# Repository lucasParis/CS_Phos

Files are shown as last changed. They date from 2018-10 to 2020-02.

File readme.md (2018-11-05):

Phos
===

USB Serial Protocol for Led Controllers
---
There is one led controller per side of the led pilar.
Each controller is being streamed frames 60 times a second of the leds' brightness by USB serial.
The protocol for the serial transmition consists of a __start byte of 255__ followed by a __list of 3564 bytes of brightness values between 0 and 254__.
These brightness values correspond to each pixel of the strip in series. The strips are arranged in 9 colomns, each with 11 modules of 36pixels long -i.e. 396 leds per colomn.
The data is listed one colomn after the other, starting and the top of the left colomn and making it's way down and then to the next colomn.
Serial baud is 2500000.

Arduino
---
- FastLED version 3.1.6
- Arduino 1.8.2
- Teensyloader 1.26

The best settings to avoid glitches in the apa102 data seems to be:
- teensy clock speed set to 144mhz
- fastled rate 3mhz

Serial baud is 2500000.

The _testCode_ firmware of prototype 2 loops 2 white leds through the strip.

Assembly
---
ribbon cables
power

TouchDesigner patch
---
### prototype 1
Test patch with internally generated patterns and UI to adjust patterns
### prototype 2
streaming patch, with syphon/spout input (to do).
- [ ] add syphon/spout input
- [ ] cleanup UI
- [ ] adapt test patterns from prototype 1
- [ ] add processing example code
- [ ] change total output for only 3 boxes, 1 side

Files
---
- prototype 1
  - Made in september 2018 for tests at the barbican
  - 1 box, 5 strips
- prototype 2
  - Made in October/November 2018
  - 3 boxes, 9 strips, 2 sides
  - custom pcbs version 1, with small changes needed
  - digikey BOMs

BOMs
---

#### BOM_leds_oneBoxSide_digikey

Bill of materials for 1 side of the box, includes power supply and connectors for 6 led breakout pcbs.
2 needed per box.

####  BOM_masterModule_digikey

Bill of materials for master module

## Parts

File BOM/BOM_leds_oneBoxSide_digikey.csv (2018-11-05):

Manufacturer Part Number | Manufacturer | Digi-Key Part Number | Customer Reference | Reference Designator | Packaging | Part Status | Quantity | Unit Price | Extended Price | Quantity Available | Mfg Std Lead Time | Description | RoHS Status | Lead Free Status | REACH Status
OSTYK42102030 | On Shore Technology Inc. | ED2945-ND |  |  | Bulk | Active | 6 | 1.18000 | $7.08 | 9870 | 12 Weeks | CONN BARRIER STRIP 2CIRC 0.325" | RoHS Compliant | Lead free | REACH Unaffected
5-520314-4 | TE Connectivity AMP Connectors | A123168-ND |  |  | Tray | Active | 18 | 0.82800 | $14.90 | 4437 | 18 Weeks | CONN FFC FPC TOP 4POS 2.54MM R/A | RoHS Compliant | Lead free | Not Available
30310-6002HB | 3M | 30310-6002HB-ND |  |  | Bulk | Active | 6 | 0.91000 | $5.46 | 18679 | 7 Weeks | CONN HEADER 10POS DL STR GOLD | RoHS Compliant | Lead free | Not Available
UHP-200A-5 | MEAN WELL USA Inc. | 1866-5498-ND |  |  | Box | Active | 1 | 69.31000 | $69.31 | 45 | Not Available | AC/DC CONVERTER 5V 200W | RoHS Compliant | Lead free | Not Available
D89110-0131HK-3365/10-D-3 | 3M | 3M156030-MC10G-3M156030-3-ND |  |  | Bulk | Active | 3 | 2.25000 | $6.75 | 237 | Not Available | CABLE 10POS SOCKET TO SOCKET 3" | RoHS Compliant | Lead free | Not Available
AK500-OE-11-1.5 | Assmann WSW Components | AE9912-ND |  |  | Bulk | Active | 1 | 6.82000 | $6.82 | 1189 | 20 Weeks | CORD SVT 18AWG 3COND 1.5M BLK | RoHS Compliant | Lead free | REACH Unaffected
0190980018 | Molex, LLC | WM13758-ND |  |  | Bulk | Active | 18 | 0.24600 | $4.42 | 4260 | 4 Weeks | CONN SPADE TERM 18-22AWG #6 | RoHS Compliant | Lead free | REACH Unaffected

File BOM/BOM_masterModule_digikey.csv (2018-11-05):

Manufacturer Part Number | Manufacturer | Digi-Key Part Number | Customer Reference | Reference Designator | Packaging | Part Status | Quantity | Unit Price | Extended Price | Quantity Available | Mfg Std Lead Time | Description | RoHS Status | Lead Free Status | REACH Status
SN74HCT245DWR | Texas Instruments | 296-1208-1-ND |  |  | Cut Tape (CT) | Active | 3 | 1.06000 | $3.18 | 11714 | 8 Weeks | IC TXRX NON-INVERT 5.5V 20SOIC | RoHS Compliant | Lead free | REACH Unaffected
4816P-T01-101LF | Bourns Inc. | 4816P-T01-101LF-ND |  |  | Tube | Active | 3 | 1.69000 | $5.07 | 548 | 7 Weeks | RES ARRAY 8 RES 100 OHM 16SOIC | RoHS Compliant | Lead free | REACH Unaffected
30310-6002HB | 3M | 30310-6002HB-ND |  |  | Bulk | Active | 3 | 0.91000 | $2.73 | 18679 | 7 Weeks | CONN HEADER 10POS DL STR GOLD | RoHS Compliant | Lead free | Not Available
OSTVN02A150 | On Shore Technology Inc. | ED10561-ND |  |  | Bulk | Active | 1 | 1.29000 | $1.29 | 33001 | 12 Weeks | CONN TERM BLOCK 2.54MM 2POS PCB | RoHS Compliant | Lead free | REACH Unaffected
61729-0010BLF | Amphenol FCI | 609-1039-ND |  |  | Tube | Active | 1 | 1.37000 | $1.37 | 32899 | 8 Weeks | CONN RCPT USB TYPE B R/A PCB | RoHS Compliant | Lead free | Not Available
GRM31CR71H105KA61L | Murata Electronics North America | 490-3908-1-ND |  |  | Cut Tape (CT) | Active | 3 | 0.55000 | $1.65 | 20000 | Not Available | CAP CER 1UF 50V X7R 1206 | RoHS Compliant | Lead free | Not Available
DEV-14057 | SparkFun Electronics | 1568-1442-ND |  |  | Bulk | Active | 1 | 46.02000 | $46.02 | 1141 | 8 Weeks | TEENSY 3.6 | Not applicable | Lead free | Not Available
HDR100IMP40F-G-V-TH | Chip Quik Inc. | HDR100IMP40F-G-V-TH-ND |  |  | Bulk | Active | 2 | 1.54000 | $3.08 | 1697 | 4 Weeks | 0.1" 40 PIN VERTICAL FEMALE HEAD | RoHS Compliant | Lead free | REACH Unaffected
61304011121 | Wurth Electronics Inc. | 732-5334-ND |  |  | Bag | Active | 2 | 2.04000 | $4.08 | 2631 | 14 Weeks | CONN HEADER 40 POS 2.54 | RoHS Compliant | Lead free | REACH Unaffected
H3DDH-1018G | Assmann WSW Components | H3DDH-1018G-ND |  |  | Bulk | Active | 3 | 2.14000 | $6.42 | 0 | Not Available | IDC CBL - HHKR10H/AE10G/HHKR10H | RoHS Compliant | Lead free | REACH Unaffected

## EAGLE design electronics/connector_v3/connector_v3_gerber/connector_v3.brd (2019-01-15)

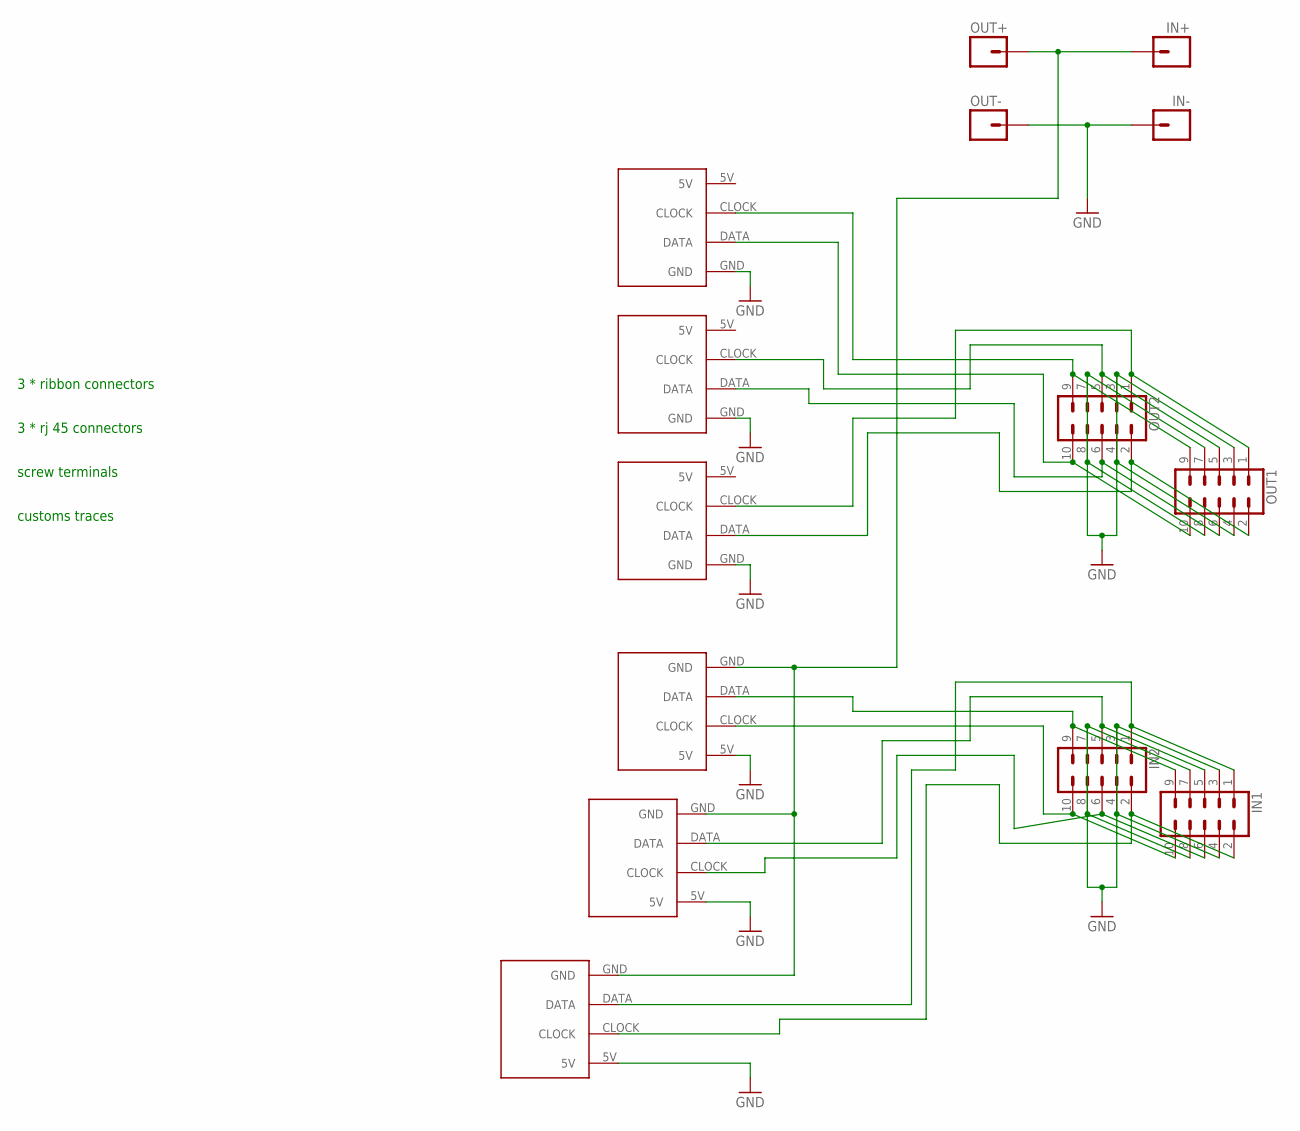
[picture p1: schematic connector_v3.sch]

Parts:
IN1, IN2: CONN_05X2SHD_LOCK; 2X5-SHROUDED_LOCK
IN+: M01PTH_2MM; 1X01_2MM
IN-: M01PTH_2MM; 1X01_2MM
INSTRIP1, INSTRIP2, INSTRIP3: APA102STRIP
OUT1, OUT2: CONN_05X2SHD_LOCK; 2X5-SHROUDED_LOCK
OUT+: M01PTH_2MM; 1X01_2MM
OUT-: M01PTH_2MM; 1X01_2MM
OUTSTRIP1, OUTSTRIP2, OUTSTRIP3: APA102STRIP

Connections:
GND: IN1.3, IN1.4, IN1.7, IN1.8, IN2.3, IN2.4, IN2.7, IN2.8, IN-.1, INSTRIP1.5V, INSTRIP2.5V, INSTRIP3.5V, OUT1.3, OUT1.4, OUT1.7, OUT1.8, OUT2.3, OUT2.4, OUT2.7, OUT2.8, OUT-.1, OUTSTRIP1.GND, OUTSTRIP2.GND, OUTSTRIP3.GND
unnamed: IN1.9, IN2.9, INSTRIP3.DATA
unnamed: IN1.10, IN2.10, INSTRIP3.CLOCK
unnamed: IN1.5, IN2.5, INSTRIP2.DATA
unnamed: IN1.6, IN2.6, INSTRIP2.CLOCK
unnamed: IN1.1, IN2.1, INSTRIP1.DATA
unnamed: IN1.2, IN2.2, INSTRIP1.CLOCK
unnamed: IN+.1, INSTRIP1.GND, INSTRIP2.GND, INSTRIP3.GND, OUT+.1
unnamed: OUT1.9, OUT2.9, OUTSTRIP3.CLOCK
unnamed: OUT1.10, OUT2.10, OUTSTRIP3.DATA
unnamed: OUT1.5, OUT2.5, OUTSTRIP2.CLOCK
unnamed: OUT1.6, OUT2.6, OUTSTRIP2.DATA
unnamed: OUT1.1, OUT2.1, OUTSTRIP1.CLOCK
unnamed: OUT1.2, OUT2.2, OUTSTRIP1.DATA

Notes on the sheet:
3 * rj 45 connectors
3 * ribbon connectors
screw terminals
customs traces

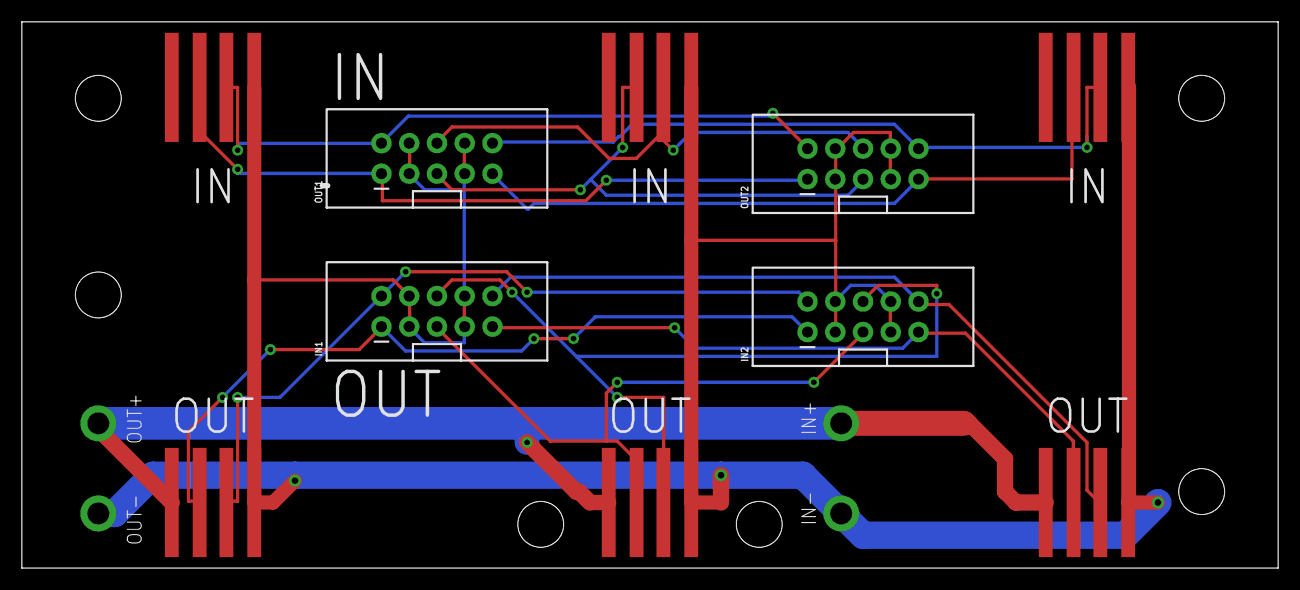
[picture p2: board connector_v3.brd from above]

Board: 2 copper layers, 115.0 x 50.0 mm, 14 parts (0 on the bottom side), 14 nets.

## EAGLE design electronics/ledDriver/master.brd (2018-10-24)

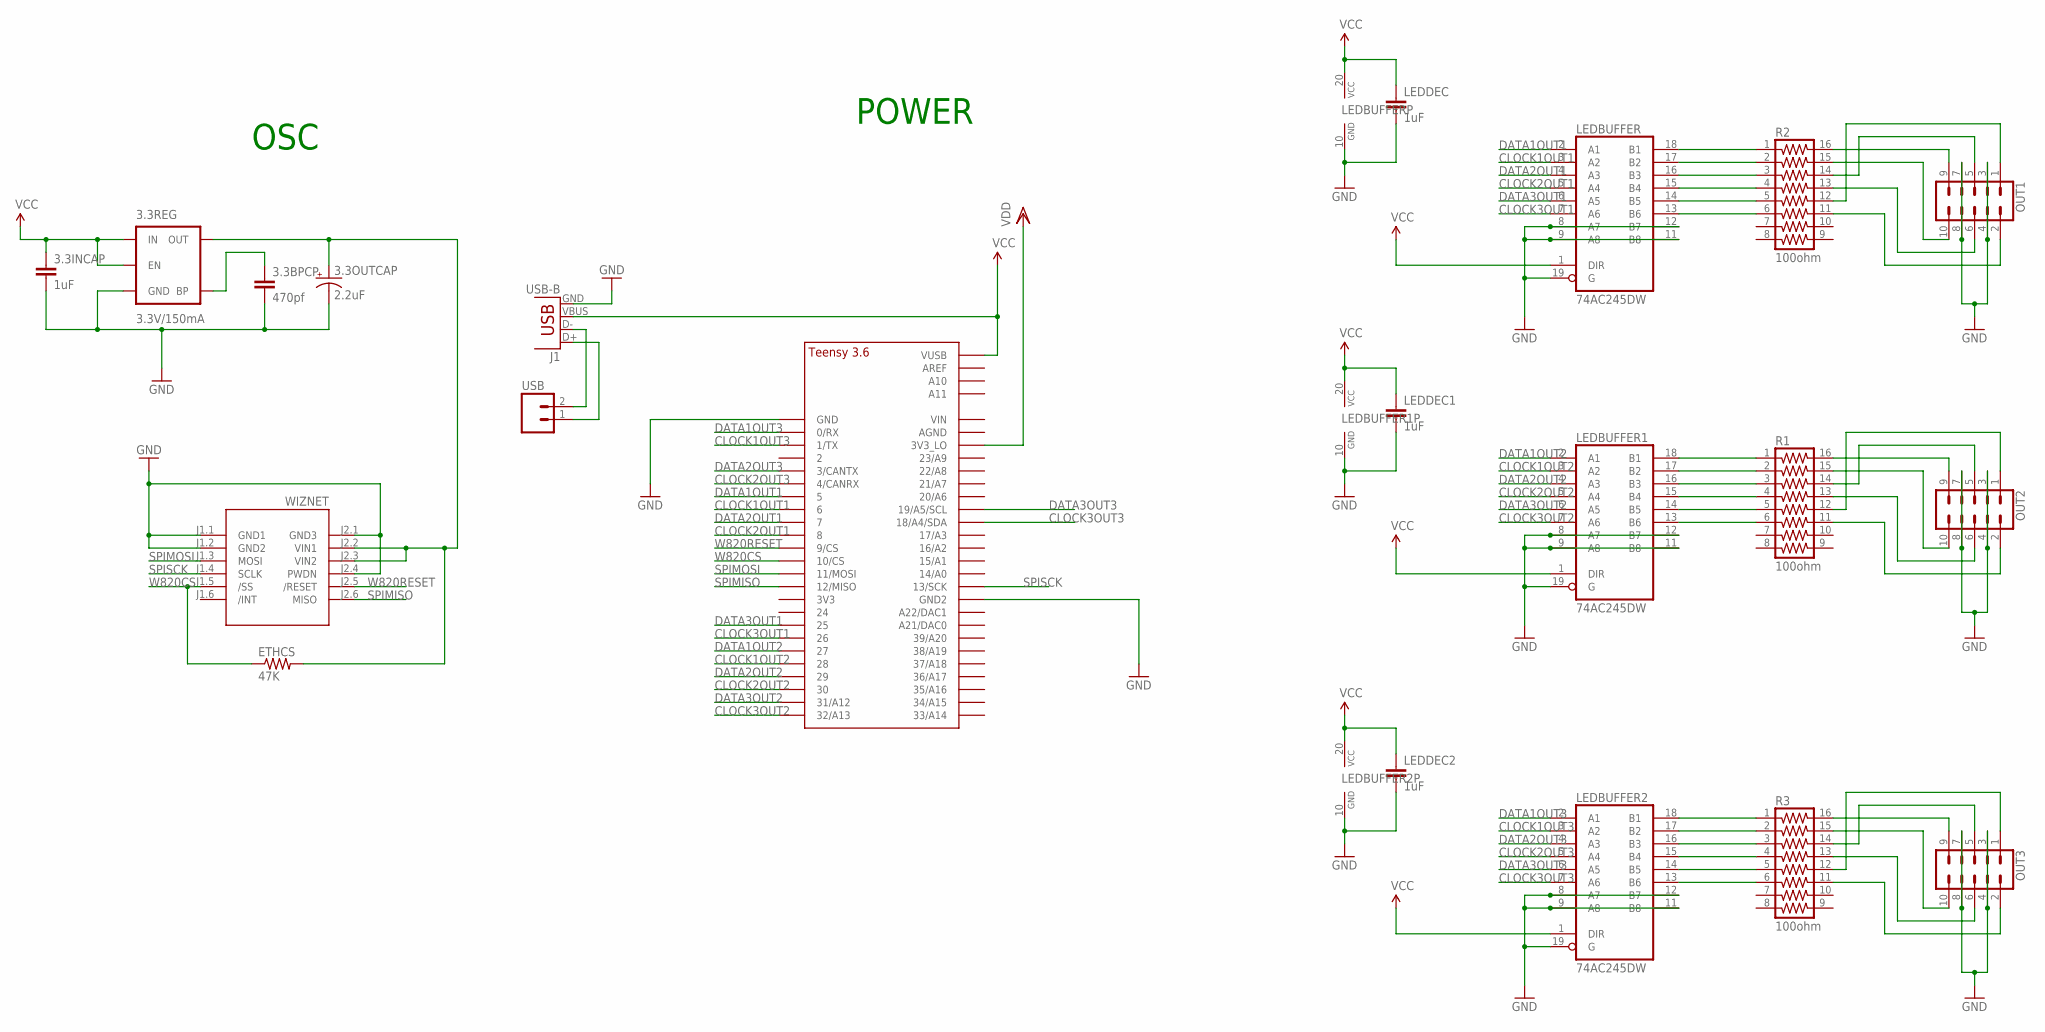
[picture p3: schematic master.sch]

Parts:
3.3BPCP: 470pf; 1206
3.3INCAP: 1uF; 1206
3.3OUTCAP: 2.2uF; EIA3528-KIT
3.3REG: 3.3V/150mA; SOT23-5
ETHCS: 47K; 1206
J1: USB-B; USB-B-PTH
LEDBUFFER, LEDBUFFER1, LEDBUFFER2: 74AC245DW; SO20W
LEDDEC, LEDDEC1, LEDDEC2: 1uF; 1206
OUT1, OUT2, OUT3: CONN_05X2SHD_LOCK; 2X5-SHROUDED_LOCK
R1, R2, R3: 100ohm; SO16
U$1: TEENSY_3.5/3.6_BASIC
USB: M02LOCK_LONGPADS; 1X02_LOCK_LONGPADS
WIZNET: WIZ820IO_DEVICE'DUAL-IN-LINE'; WIZ820IO

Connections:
CLOCK1OUT1: LEDBUFFER.3 (A2), U$1.6
CLOCK1OUT2: LEDBUFFER1.3 (A2), U$1.28
CLOCK1OUT3: LEDBUFFER2.3 (A2), U$1.1/TX
CLOCK2OUT1: LEDBUFFER.5 (A4), U$1.8
CLOCK2OUT2: LEDBUFFER1.5 (A4), U$1.30
CLOCK2OUT3: LEDBUFFER2.5 (A4), U$1.4/CANRX
CLOCK3OUT1: LEDBUFFER.7 (A6), U$1.26
CLOCK3OUT2: LEDBUFFER1.7 (A6), U$1.32/A13
CLOCK3OUT3: LEDBUFFER2.7 (A6), U$1.18/A4/SDA
DATA1OUT1: LEDBUFFER.2 (A1), U$1.5
DATA1OUT2: LEDBUFFER1.2 (A1), U$1.27
DATA1OUT3: LEDBUFFER2.2 (A1), U$1.0/RX
DATA2OUT1: LEDBUFFER.4 (A3), U$1.7
DATA2OUT2: LEDBUFFER1.4 (A3), U$1.29
DATA2OUT3: LEDBUFFER2.4 (A3), U$1.3/CANTX
DATA3OUT1: LEDBUFFER.6 (A5), U$1.25
DATA3OUT2: LEDBUFFER1.6 (A5), U$1.31/A12
DATA3OUT3: LEDBUFFER2.6 (A5), U$1.19/A5/SCL
GND: 3.3BPCP.2, 3.3INCAP.2, 3.3OUTCAP.C (-), 3.3REG.2 (GND), J1.GND, LEDBUFFER.8 (A7), LEDBUFFER.9 (A8), LEDBUFFER.10 (GND), LEDBUFFER.11 (B8), LEDBUFFER.12 (B7), LEDBUFFER.19 (G), LEDBUFFER1.8 (A7), LEDBUFFER1.9 (A8), LEDBUFFER1.10 (GND), LEDBUFFER1.11 (B8), LEDBUFFER1.12 (B7), LEDBUFFER1.19 (G), LEDBUFFER2.8 (A7), LEDBUFFER2.9 (A8), LEDBUFFER2.10 (GND), LEDBUFFER2.11 (B8), LEDBUFFER2.12 (B7), LEDBUFFER2.19 (G), LEDDEC.2, LEDDEC1.2, LEDDEC2.2, OUT1.3, OUT1.4, OUT1.7, OUT1.8, OUT2.3, OUT2.4, OUT2.7, OUT2.8, OUT3.3, OUT3.4, OUT3.7, OUT3.8, U$1.GND, U$1.GND2, WIZNET.J1.1 (GND1), WIZNET.J1.2 (GND2), WIZNET.J2.1 (GND3), WIZNET.J2.4 (PWDN)
unnamed: J1.D+, USB.1
unnamed: LEDBUFFER.18 (B1), R2.1
unnamed: LEDBUFFER.17 (B2), R2.2
unnamed: LEDBUFFER.16 (B3), R2.3
unnamed: J1.D-, USB.2
unnamed: LEDBUFFER.15 (B4), R2.4
unnamed: LEDBUFFER.14 (B5), R2.5
unnamed: 3.3OUTCAP.A (+), 3.3REG.5 (OUT), ETHCS.2, WIZNET.J2.2 (VIN1), WIZNET.J2.3 (VIN2)
unnamed: OUT1.9, R2.16
unnamed: OUT1.10, R2.15
unnamed: OUT1.5, R2.14
unnamed: OUT1.6, R2.13
unnamed: OUT1.1, R2.12
unnamed: OUT1.2, R2.11
unnamed: LEDBUFFER1.18 (B1), R1.1
unnamed: LEDBUFFER1.17 (B2), R1.2
unnamed: LEDBUFFER.13 (B6), R2.6
unnamed: LEDBUFFER1.16 (B3), R1.3
unnamed: LEDBUFFER1.15 (B4), R1.4
unnamed: LEDBUFFER1.14 (B5), R1.5
unnamed: LEDBUFFER1.13 (B6), R1.6
unnamed: OUT2.9, R1.16
unnamed: OUT2.10, R1.15
unnamed: OUT2.5, R1.14
unnamed: OUT2.6, R1.13
unnamed: OUT2.1, R1.12
unnamed: OUT2.2, R1.11
unnamed: LEDBUFFER2.18 (B1), R3.1
unnamed: LEDBUFFER2.17 (B2), R3.2
unnamed: LEDBUFFER2.16 (B3), R3.3
unnamed: LEDBUFFER2.15 (B4), R3.4
unnamed: LEDBUFFER2.14 (B5), R3.5
unnamed: LEDBUFFER2.13 (B6), R3.6
unnamed: OUT3.9, R3.16
unnamed: OUT3.10, R3.15
unnamed: OUT3.5, R3.14
unnamed: OUT3.6, R3.13
unnamed: OUT3.1, R3.12
unnamed: OUT3.2, R3.11
unnamed: 3.3BPCP.1, 3.3REG.4 (BP)
SPIMISO: U$1.12/MISO, WIZNET.J2.6 (MISO)
SPIMOSI: U$1.11/MOSI, WIZNET.J1.3 (MOSI)
SPISCK: U$1.13/SCK, WIZNET.J1.4 (SCLK)
VCC: 3.3INCAP.1, 3.3REG.1 (IN), 3.3REG.3 (EN), J1.VBUS, LEDBUFFER.1 (DIR), LEDBUFFER.20 (VCC), LEDBUFFER1.1 (DIR), LEDBUFFER1.20 (VCC), LEDBUFFER2.1 (DIR), LEDBUFFER2.20 (VCC), LEDDEC.1, LEDDEC1.1, LEDDEC2.1, U$1.VUSB
VDD: U$1.3V3_LO
W820CS: ETHCS.1, U$1.10/CS, WIZNET.J1.5 (/SS)
W820RESET: U$1.9/CS, WIZNET.J2.5 (/RESET)

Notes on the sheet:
OSC
POWER

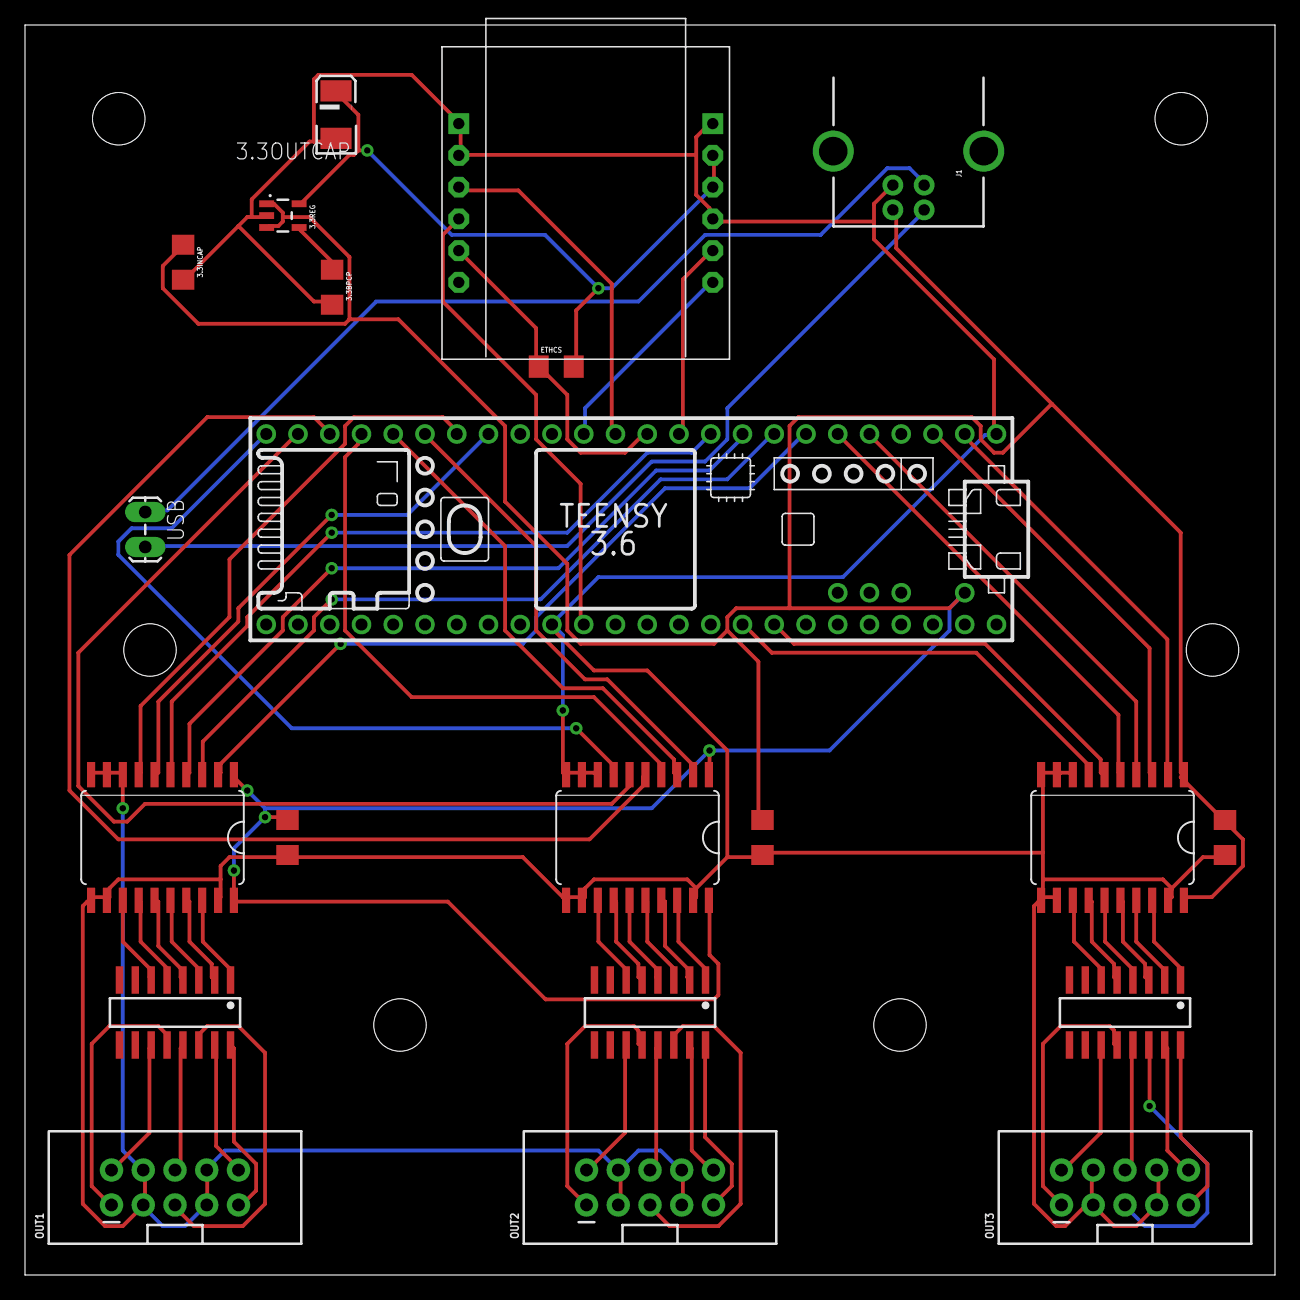
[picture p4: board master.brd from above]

Board: 2 copper layers, 100.0 x 100.0 mm, 21 parts (0 on the bottom side), 65 nets.

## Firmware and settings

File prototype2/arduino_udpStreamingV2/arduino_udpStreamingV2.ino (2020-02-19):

#include <SPI.h>
#include <Ethernet.h>
#include <EthernetUdp.h>
#define UDP_TX_PACKET_MAX_SIZE 500
#include <FastLED.h>

#define NUM_LEDS 360// 36 leds * 10 boxes, number of leds per output (9 per pcb)
CRGB leds[9][NUM_LEDS];//holds the values of the leds for fastled output
#define RATE 3 // 3 seems like the ideal value, slowdown if glitches appear at the end of the strips but watchout for dropping FPS
float lastOutputTime;//used as a counter to limit the output rate to 60fps, when lastoutputtime is bigger then current time minus 16milliseconds, sends data to leds

//set teensy at 144 mhz


EthernetUDP Udp;
IPAddress ip(10, 10, 10, 11);//ip of the arduino's ethernet chip
const unsigned int inPort = 9003;//udp port for incoming data

byte mac[] = {  0xDE, 0xAD, 0xBE, 0xEF, 0xFE, 0xED };//mac adress of the wiznet chips


void setup() {
  Serial.begin(115200);
  Ethernet.begin(mac, ip);
  Udp.begin(inPort);

   lastOutputTime = 0;
  //setup led outputs, port numbers and order tested, from the pcb schematic
  FastLED.addLeds<APA102, 5, 6, BGR, DATA_RATE_MHZ(RATE)>(leds[2], NUM_LEDS);
  FastLED.addLeds<APA102, 7, 8, BGR, DATA_RATE_MHZ(RATE)>(leds[1], NUM_LEDS);
  FastLED.addLeds<APA102, 25, 26, BGR, DATA_RATE_MHZ(RATE)>(leds[0], NUM_LEDS);
  FastLED.addLeds<APA102, 27, 28, BGR, DATA_RATE_MHZ(RATE)>(leds[5], NUM_LEDS);
  FastLED.addLeds<APA102, 29, 30, BGR, DATA_RATE_MHZ(RATE)>(leds[4], NUM_LEDS);
  FastLED.addLeds<APA102, 31, 32, BGR, DATA_RATE_MHZ(RATE)>(leds[3], NUM_LEDS);
  FastLED.addLeds<APA102, 0, 1, BGR, DATA_RATE_MHZ(RATE)>(leds[8], NUM_LEDS);
  FastLED.addLeds<APA102, 3, 4, BGR, DATA_RATE_MHZ(RATE)>(leds[7], NUM_LEDS);
  FastLED.addLeds<APA102, 19, 18, BGR, DATA_RATE_MHZ(RATE)>(leds[6], NUM_LEDS);

}

void loop() {
  // put your main code here, to run repeatedly:
  //  Serial.println("waiting");

  int packetSize = Udp.parsePacket();//check if incoming data is available
  if (packetSize) {
//    Serial.println("got");
    char packetBuffer[UDP_TX_PACKET_MAX_SIZE];

    //reading udp
    // buffer to hold incoming packet
    //      for(int i = 0 ; i< UDP_TX_PACKET_MAX_SIZE; i++)
    //      {
    //        packetBuffer[i]= 0;
    //      }
    Udp.read(packetBuffer, UDP_TX_PACKET_MAX_SIZE); //reading udp data into the buffer
    //        Serial.print("udppdppd!   ");
    //    IPAddress remote = Udp.remoteIP();
    //        Serial.print(packetSize);
    //        Serial.println(remote);

    int x = int(packetBuffer[0]);
//    Serial.println(x);
    for (int y = 0; y < 360; y++)
    {

      int value = int(packetBuffer[1+y]);
      leds[x][y].red = value;
      leds[x][y].green = value;
      leds[x][y].blue = value;
//      Serial.println(int(packetBuffer[i]));
    }


  }
//fastled output
  if (millis() - lastOutputTime   > 15)//check if it's been 15 milliseconds since last output (don't want to output too fast)
  {
//    for (int x = 0; x < 9; x++)//loop trough the 9 led strips outputs
//    {
//      for (int i = 0; i < 36; i++)//loop through the first 36 leds of the strip (change 36 to 386 for the 11 boxes)
//      {
//        int value = 0;
//        value = (x * 3 + int(millis() * 0.001 * 10)) % 36;//formula generates a pixel moving down the strip
//        value = (value == i) || (value == (i + 1));// double the pixel to get a group of 2 moving pixels
////        value = 1;// double the pixel to get a group of 2 moving pixels
//        //set led values (low brightness, multiply by 255 for full brightness
////        leds[x][i].red = int(value * 20);
////        leds[x][i].green =  int(value * 20);
////        leds[x][i].blue = int(value * 20);
//
//      }
//    }

    FastLED.show();//send led data to strips
    lastOutputTime = millis();//update time for output counter
  }

  
}

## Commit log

2018-09-24 added arduino sketch
2018-10-24 added PCB files
    [connector.brd, connector.sch, master.brd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]
2018-10-28 reorganised folders, added readme
    [connector_v1.brd, connector_v1.sch, master.brd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]
2018-10-28 version 2 of connector pcb
    [connector_v1.brd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]
2018-11-05 added BOMs
    [BOM_leds_oneBoxSide_digikey.csv, BOM_masterModule_digikey.csv]
2018-11-05 added BOM readme
2018-11-05 added arduino code for proto 2 and commented code
2019-01-15 connector v3 added mirrored connector to the side
    [connector_v3.brd, connector_v3.sch]
2019-02-13 new pcb version and update TD with processing code
    [connector_v3.brd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]

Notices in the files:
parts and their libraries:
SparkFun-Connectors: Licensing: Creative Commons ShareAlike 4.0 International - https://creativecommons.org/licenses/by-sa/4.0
